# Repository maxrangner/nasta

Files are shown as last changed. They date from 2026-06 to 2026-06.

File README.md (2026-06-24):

# <b><p align="center">Nästa »  Mini</p></b>

<p align="center">
  A little box that tells you when the next SL (Stockholm Local Transport) departure is leaving.<br>One glance on your way out the door and you'll know if you can stroll or if you need to sprint.
</p>

<p align="center">
  
  
  
</p>

---

<p align="center">
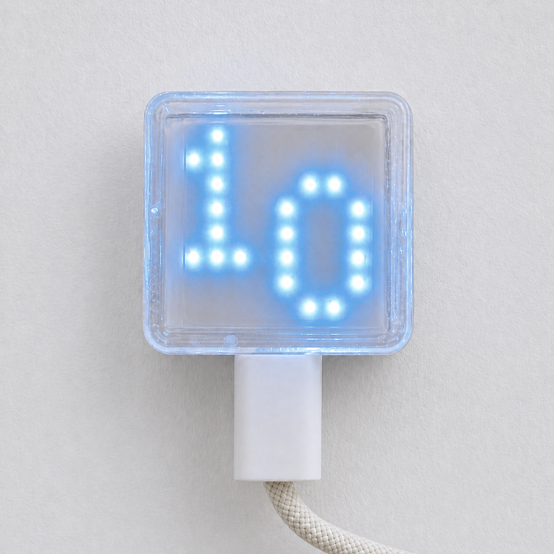
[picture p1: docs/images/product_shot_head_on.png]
Nästa Mini showing next departure
  
</p>

The <i>Nästa Mini</i> built around an ESP32-S3 with an 8×8 RGB LED matrix and a single push button on the back. Run through the setup portal once, and from then on it just sits there showing your next departure in a color that does the thinking for you.

| Color | Meaning |
|---|---|
|  | means you're already too late.
|  | means hurry up.
|  or  |  means relax, take your time.

It only shows one direction at a time, but switching is easy: a short button press toggles between direction 1 and direction 2. Use one to glance at your own commute out, and the other to keep an eye on when someone else is due to arrive.

A long press drops you into setup mode.

## Setup

On first boot (or after a long button press), the device opens its own Wi-Fi access point called `nasta-mini-setup`. Connect to it and a captive portal should pop up on its own. If your phone or laptop is being stubborn about it, just open `http://setup.nasta-mini/` in a browser yourself. From there you can set:

- Your Wi-Fi credentials
- The SL site ID for your stop
- A transport mode filter (any, metro, train, bus, tram)
- Walk time in minutes (sets up when the color gradient is triggered)
- Brightness, startup direction, and display orientation

Don't know your stop's SL site ID off the top of your head? Nobody does. Look it up in Trafiklab's SL stop data tools and grab the numeric `site_id`.

## Display states

The matrix talks to you in color and the occasional symbol. Here's the full vocabulary:

| &nbsp; | State | Meaning |
|:---:|---|---|
|  | Boot animation | Starting up |
|  | Color wheel | Connecting to Wi-Fi |
|  | Green "OK" | Connected, waiting for first data |
|  | Pulsating white animation | Setup mode |
|  | Color ramp | Departure in N minutes. Color reflects urgency |
|  | Yellow `?` | No departures available |
|  | Red `?` | API error |
|  | Red `x` | Network error |

## Hardware

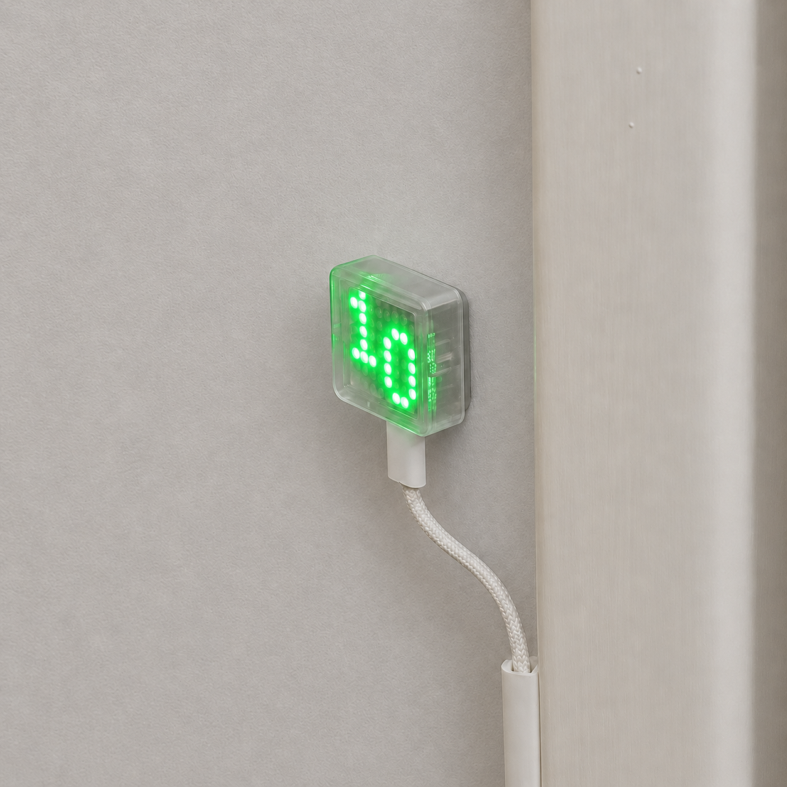
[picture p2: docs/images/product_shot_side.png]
Nästa Mini mounted on a wall


Built and tested on the [Waveshare ESP32-S3-Matrix](https://www.waveshare.com/esp32-s3-matrix.htm) development board, which already packages the ESP32-S3 and the 8×8 RGB LED matrix together. The only thing added on afterward is a push button on the back.

- **MCU**: ESP32-S3
- **Display**: 8×8 RGB LED matrix
- **Input**: one push button

The electronics lives inside a two-part 3D printed case. Print files are in [hardware/3d-print/](hardware/3d-print/):

- [`front_v.1.0.3mf`](hardware/3d-print/front_v.1.0.3mf)
- [`back_v.1.0.3mf`](hardware/3d-print/back_v.1.0.3mf)

## API

Departures come from the [SL Transport API](https://www.trafiklab.se/sv/api/our-apis/sl/transport/), polled every 10 seconds. Only departures with state `EXPECTED` make the cut.

This product is based on information retrieved from [Trafiklab.se](https://www.trafiklab.se/).

## Building

Tested with ESP-IDF `v5.5.3` for target `esp32s3`.

Open an ESP-IDF shell and build/flash like you would any other ESP-IDF project:

```sh
idf.py set-target esp32s3
idf.py build
idf.py -p <PORT> flash monitor
```

Thanks for reading, now go catch your ride!

## License
This repository is source-available, not open source. See [LICENSE](LICENSE) for the governing terms.

Third-party software notices live in [THIRD-PARTY-NOTICES.md](THIRD-PARTY-NOTICES.md).

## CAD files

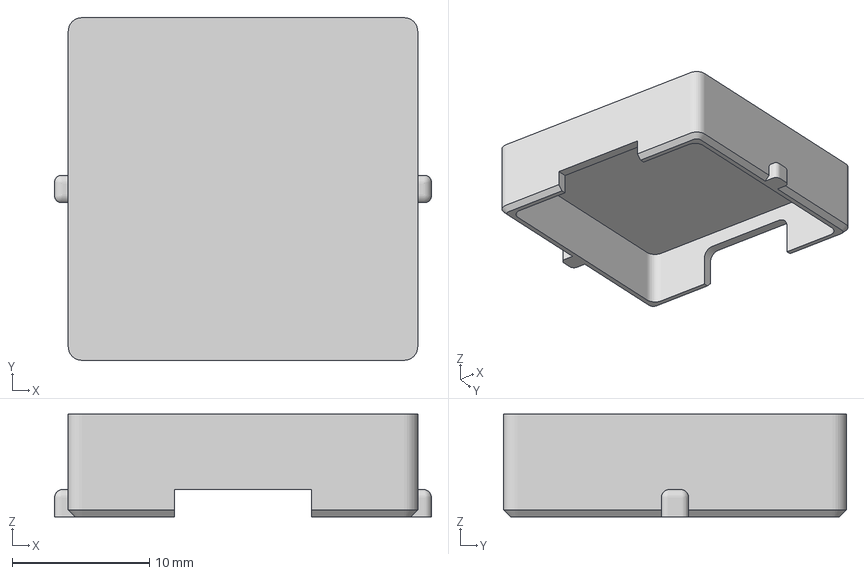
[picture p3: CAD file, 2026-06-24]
hardware/3d-print/back_v.1.0.3mf
27.5 x 25.0 x 7.50 mm

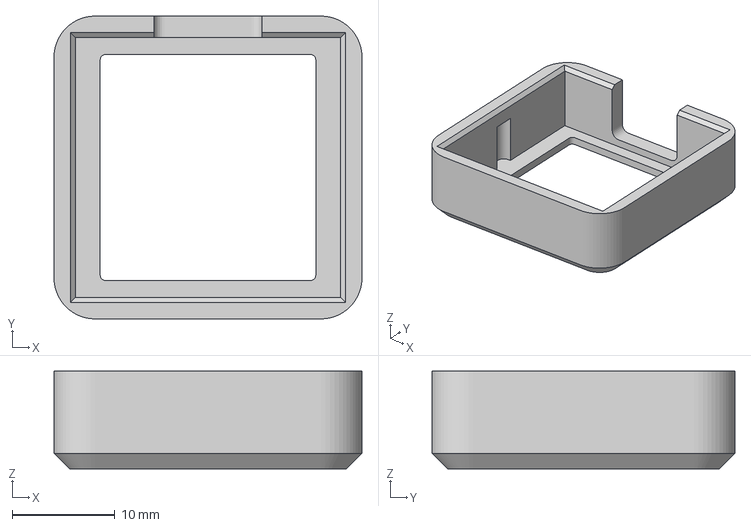
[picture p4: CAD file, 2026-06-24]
hardware/3d-print/front_v.1.0.3mf
30.0 x 29.5 x 9.50 mm

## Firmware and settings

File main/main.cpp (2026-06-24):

#include "freertos/FreeRTOS.h"
#include "freertos/task.h"
#include "app_context.h"
#include "display.h"
#include "system_manager.h"
#include "network_manager.h"
#include "message_types.h"
#include "system_init.h"

extern "C" void app_main(void)
{
    systemInit();

    static Queues queues = {
        .system_in_queue = xQueueCreate(kSystemQueueLength, sizeof(SystemEvent)),
        .network_in_queue = xQueueCreate(kNetworkQueueLength, sizeof(NetworkCommand)),
    };

    static Display display;
    static SystemManager system_manager(&queues, &display);
    static NetworkManager network_manager(&queues);
    
    display.init();
    network_manager.init();
    system_manager.init();
}

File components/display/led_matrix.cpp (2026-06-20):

#include "led_matrix.h"

#include "esp_err.h"
#include "matrix_animations.h"
#include "matrix_graphics.h"
#include "soc/soc_caps.h"
#include <string.h>

namespace {

struct RgbColor {
    uint8_t red;
    uint8_t green;
    uint8_t blue;
};

static constexpr uint8_t kCenterRings[64] = {
    6,5,4,3,3,4,5,6,
    5,4,3,2,2,3,4,5,
    4,3,2,1,1,2,3,4,
    3,2,1,0,0,1,2,3,
    3,2,1,0,0,1,2,3,
    4,3,2,1,1,2,3,4,
    5,4,3,2,2,3,4,5,
    6,5,4,3,3,4,5,6
};

static constexpr uint8_t kSetupLevels[7] = { 0, 1, 2, 4, 6, 8, 10 };

static uint8_t lerpChannel(uint8_t from, uint8_t to, uint8_t blend) {
    const uint16_t start = static_cast<uint16_t>(from) * (255 - blend);
    const uint16_t end = static_cast<uint16_t>(to) * blend;
    return static_cast<uint8_t>((start + end) / 255);
}

static RgbColor rainbowColor(uint8_t brightness, uint8_t hue) {
    const RgbColor kStops[6] = {
        {brightness, 0, 0},
        {brightness, brightness, 0},
        {0, brightness, 0},
        {0, brightness, brightness},
        {0, 0, brightness},
        {brightness, 0, brightness},
    };

    const uint16_t scaled = static_cast<uint16_t>(hue) * 6;
    const uint8_t segment = (scaled / 256) % 6;
    const uint8_t blend = scaled % 256;
    const RgbColor from = kStops[segment];
    const RgbColor to = kStops[(segment + 1) % 6];

    return {
        lerpChannel(from.red, to.red, blend),
        lerpChannel(from.green, to.green, blend),
        lerpChannel(from.blue, to.blue, blend),
    };
}

}

void LedMatrix::init() {
    led_strip_config_t strip_config = {
        .strip_gpio_num = kLedPin_,
        .max_leds = kLedCount_,
        .led_model = LED_MODEL_WS2812,
        .color_component_format = LED_STRIP_COLOR_COMPONENT_FMT_RGB,
        .flags = { .invert_out = false },
    };
    led_strip_rmt_config_t rmt_config = {
        .clk_src = RMT_CLK_SRC_DEFAULT,
        .resolution_hz = 10 * 1000 * 1000,
        .mem_block_symbols = 256,
        .flags = {
#if SOC_RMT_SUPPORT_DMA
            .with_dma = true,
#else
            .with_dma = false,
#endif
        },
    };
    ESP_ERROR_CHECK(led_strip_new_rmt_device(&strip_config, &rmt_config, &led_strip_));
    ESP_ERROR_CHECK(led_strip_clear(led_strip_));
    memset(pixel_buffer_, 0, sizeof(pixel_buffer_));
    frame_dirty_ = false;
}

void LedMatrix::setBrightness(uint8_t brightness) {
    brightness_ = brightness;
}

void LedMatrix::clear() {
    if (led_strip_ == nullptr) return;
    ESP_ERROR_CHECK(led_strip_clear(led_strip_));
    memset(pixel_buffer_, 0, sizeof(pixel_buffer_));
    frame_dirty_ = false;
}

void LedMatrix::showBootFrame(uint32_t frame) {
    setColor(brightness_, brightness_, brightness_);
    drawGraphic(kBootAnimation[frame % kBootFrameCount]);
}

void LedMatrix::showConnecting(uint32_t frame) {
    const uint8_t hue = static_cast<uint8_t>(frame * 9);
    const RgbColor color = rainbowColor(brightness_, hue);

    setColor(color.red, color.green, color.blue);
    drawGraphic(kWorkAnimation[frame % 4]);
}

void LedMatrix::showConnected() {
    setColor(0, brightness_, 0);
    drawGraphic(kOk);
}

// void LedMatrix::showSetup() {
//     setColor(0, brightness_, 0);
//     drawGraphic(kHeart);
// }

void LedMatrix::showSetup(uint32_t frame) {
    if (led_strip_ == nullptr) return;

    const uint8_t phase = (frame / 1) % 7;

    for (uint16_t i = 0; i < kLedCount_; i++) {
        const uint8_t level = kSetupLevels[(kCenterRings[i] + phase) % 7];
        setPixel(i, level, level, level);
    }

    refreshIfDirty();
}

void LedMatrix::showDepartureMinutes(uint8_t minutes, uint8_t r, uint8_t g, uint8_t b) {
    setColor(r, g, b);
    displayNumber(minutes);
}

void LedMatrix::showDepartureClock(const char* time_str, uint32_t frame, uint8_t r, uint8_t g, uint8_t b) {
    setColor(r, g, b);

    if (time_str == nullptr) {
        drawGraphic(kQuestion);
        return;
    }

    displayClock(time_str, frame);
}

void LedMatrix::showDepartureUnknown() {
    setColor(brightness_, brightness_, 0);
    drawGraphic(kQuestion);
}

void LedMatrix::showNoDepartures() {
    setColor(brightness_, brightness_, 0);
    drawGraphic(kQuestion);
}

void LedMatrix::showApiError() {
    setColor(brightness_, 0, 0);
    drawGraphic(kQuestion);
}

void LedMatrix::showNetworkError() {
    setColor(brightness_, 0, 0);
    drawGraphic(kCross);
}

void LedMatrix::showDirectionLeft() {
    setColor(brightness_, brightness_, brightness_);
    drawGraphic(kArrowLeft);
}

void LedMatrix::showDirectionRight() {
    setColor(brightness_, brightness_, brightness_);
    drawGraphic(kArrowRight);
}

void LedMatrix::setPixel(uint16_t index, uint8_t r, uint8_t g, uint8_t b) {
    if (pixel_buffer_[index][0] == r &&
        pixel_buffer_[index][1] == g &&
        pixel_buffer_[index][2] == b) {
        return;
    }
    pixel_buffer_[index][0] = r;
    pixel_buffer_[index][1] = g;
    pixel_buffer_[index][2] = b;
    frame_dirty_ = true;
    ESP_ERROR_CHECK(led_strip_set_pixel(led_strip_, index, r, g, b));
}

void LedMatrix::refreshIfDirty() {
    if (led_strip_ == nullptr || !frame_dirty_) return;
    ESP_ERROR_CHECK(led_strip_refresh(led_strip_));
    frame_dirty_ = false;
}

void LedMatrix::setColor(uint8_t r, uint8_t g, uint8_t b) {
    red_   = r;
    green_ = g;
    blue_  = b;
}

void LedMatrix::drawGraphic(const uint8_t* graphic) {
    if (led_strip_ == nullptr || graphic == nullptr) return;
    for (uint16_t i = 0; i < kLedCount_; i++) {
        if (graphic[i] == 1) {
            setPixel(i, red_, green_, blue_);
        } else {
            setPixel(i, 0, 0, 0);
        }
    }
    refreshIfDirty();
}

void LedMatrix::scrollGraphics(const uint8_t** graphics, uint8_t count, uint32_t frame, uint8_t speed) {
    if (led_strip_ == nullptr || graphics == nullptr || count == 0) return;

    const int8_t  spacing      = -2;
    const uint8_t col_offset   = 1;
    const uint8_t graphic_width = 8;
    uint32_t      scroll_offset = (frame * speed) / 10;

    for (uint8_t row = 0; row < kMatrixWidth_; row++) {
        for (uint8_t col = 0; col < kMatrixWidth_; col++) {
            uint32_t logical_col = col + scroll_offset;
            uint8_t  gi          = (logical_col / (graphic_width + spacing)) % count;
            uint8_t  gc          = (logical_col % (graphic_width + spacing)) + col_offset;
            uint8_t  pixel       = graphics[gi][row * graphic_width + gc];
            uint16_t led         = row * kMatrixWidth_ + col;
            if (pixel == 1) {
                setPixel(led, red_, green_, blue_);
            } else {
                setPixel(led, 0, 0, 0);
            }
        }
    }
    refreshIfDirty();
}

void LedMatrix::displayNumber(uint8_t number) {
    if (number > 30) {
        drawGraphic(kThirtyPlus);
        return;
    }
    drawGraphic(kNumbers[number]);
}
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

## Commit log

2026-02-24 Move previous Arduino implementation to legacy folder
2026-06-01 Wire up boot and network flow
2026-06-02 Fix setup mode disconnect edge case
2026-06-03 Fix WS2812 display glitch
    [led_matrix.cpp]
2026-06-03 Fix stack overflow on button press
2026-06-18 Refactor SystemManager and display animation flow
2026-06-24 Prepare Nästa Mini v1.0.0 release
    [back_v.1.0.3mf, front_v.1.0.3mf]
